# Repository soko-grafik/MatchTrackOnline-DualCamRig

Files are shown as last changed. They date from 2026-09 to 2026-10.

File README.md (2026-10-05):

# 📷 Dual DJI Osmo Action 4 Rig (80° V-Mount)






<p align="center">
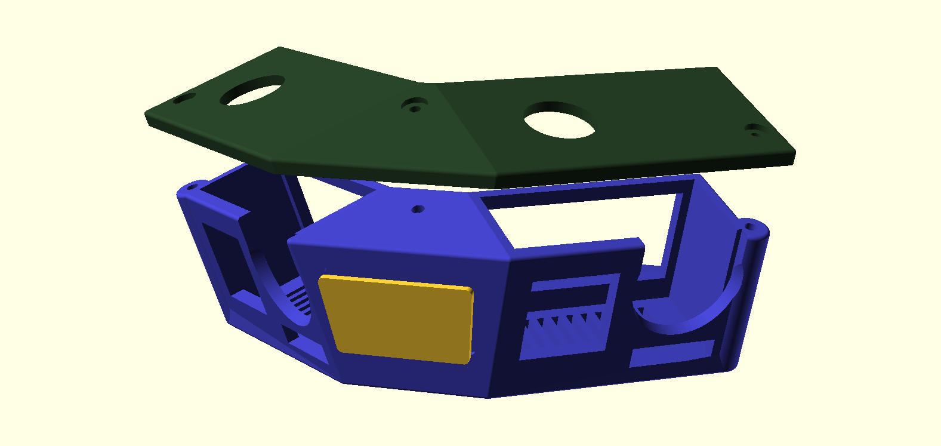
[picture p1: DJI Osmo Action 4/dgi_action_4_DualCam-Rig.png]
Dual DJI Osmo Action 4 Rig Preview
  
</p>

Ein professionelles, vollständig parametrisches 3D-Druck-Rig für **zwei DJI Osmo Action 4** Kameras, konstruiert in **OpenSCAD**.

Entwickelt für Weitwinkel-Aufzeichnungen, Stereo-Setups, Sport-Tracking und Livestreaming. Das Gehäuse bietet ein durchdachtes Kabel- und Energiemanagement mit dauerhafter USB-C-Stromversorgung, einem massiven **Rain Shield (Regenschutz)** für wetterfeste Außeneinsätze sowie einer **optionalen, in OpenSCAD zuschaltbaren Powerbank-Garage**.

---

## 📑 Inhaltsverzeichnis

- [✨ Features](#-features)
- [🛠️ Stückliste (BOM) & Hardware](#️-stückliste-bom--hardware)
- [📂 Projekt- & Dateistruktur](#-projekt--dateistruktur)
- [🖨️ 3D-Druck & Render-Modi](#️-3d-druck--render-modi)
  - [OpenSCAD Render-Modi](#openscad-render-modi)
  - [Druckempfehlungen & Slicer-Einstellungen](#druckempfehlungen--slicer-einstellungen)
- [⚙️ Parametrische Anpassung](#️-parametrische-anpassung)
- [🚀 Montageanleitung](#-montageanleitung)
- [☕ Support & Spenden](#-support--spenden)

---

## ✨ Features

- **📐 Präzise Geometrie:** 80° horizontale Spreizung und konfigurierbarer Neigungswinkel (Tilt, z. B. 20° nach unten gerichtet).
- **🌧️ Rain Shield Deckel:** Alternativer Top-Cover-Deckel mit breiter Krempe und bündigen Schraubensenkungen – maximaler Schutz vor Regen ohne Sichtfeldeinschränkung der Linsen.
- **⚡ Continuous Power:** Saubere USB-C-Aussparungen an beiden Kamera-Bays zur direkten Verkabelung für dauerhafte externe Stromversorgung.
- **🔋 Optionale Powerbank-Garage (nur via OpenSCAD):** Kann bei Bedarf parametrisch über OpenSCAD (`pb_enable = true`) im vorderen "V" des Rigs aktiviert und maßgeschneidert werden. In den beiliegenden Standard-Druckdateien (.3mf / .stl) ist das Gehäuse standardmäßig ohne Powerbank-Schacht ausgeführt.
- **❄️ Thermomanagement:** Strategisch platzierte Belüftungsschlitze (*Ventilation Slots*) verhindern Hitzestau bei Daueraufnahmen.
- **🏷️ Individualisierbar:** Frontseitig eingelassenes Trapez-Emblem für eigenes Branding (ideal für Single- oder Multi-Color-Druck).
- **🔩 Solide Stativaufnahme:** Integrierter Kragen für ein standardmäßiges 1/4"-Stativgewinde an der massiven Unterseite.

---

## 🛠️ Stückliste (BOM) & Hardware

| Komponente | Anzahl | Beschreibung / Empfehlung |
| :--- | :---: | :--- |
| **Kameras** | 2× | DJI Osmo Action 4 |
| **Gewindeeinsätze (Base)** | 3× | M3 Einschmelzmuttern / Heat-Set Inserts (z. B. Ruthex M3 × 5,7 mm) |
| **Schrauben (Deckel)** | 3× | M3 Zylinderkopf- oder Innensechskantschrauben (Länge passend zum Deckel) |
| **Stativgewinde** | 1× | 1/4"-20 UNC Gewindeeinsatz / Einschmelzmutter für Kamerastative |
| **USB-Kabel** | 2× | Kurze USB-C auf USB-C Kabel (idealerweise mit 90°-Winkelsteckern) |
| **Powerbank** *(optional)* | 1× | Nur erforderlich, falls die optionale Powerbank-Garage im SCAD-Modell aktiviert wird (`pb_enable = true`) |

---

## 📂 Projekt- & Dateistruktur

```text
├── DJI Osmo Action 4/
│   ├── dgi_action_4_DualCam-Rig.png    # 3D-Vorschau / Render-Bild
│   ├── dgi_action_4_DualCam-Rig.scad   # Parametrisches OpenSCAD-Hauptmodell
│   ├── 3mf Files/                      # Vorbereitete Slicer-Dateien (Bambu Studio / PrusaSlicer)
│   │   ├── base.3mf                    # Hauptgehäuse
│   │   ├── cover.3mf                   # Kompakter Standarddeckel
│   │   ├── cover_with_shield.3mf       # Deckel mit Regenschutz (Rain Shield)
│   │   └── emblem.3mf                  # Front-Trapez Emblem
│   └── stl Files/                      # Exportierte Standard-STLs zum Direktdruck
│       ├── base.stl
│       ├── cover.stl
│       ├── cover_with_shield.stl
│       └── emblem.stl
└── README.md                           # Dokumentation
```

---

## 🖨️ 3D-Druck & Render-Modi

### OpenSCAD Render-Modi

Die STL-Generierung der Einzelteile erfolgt über die Variable `RENDER_MODE` im Quellcode ([`dgi_action_4_DualCam-Rig.scad`](./DJI%20Osmo%20Action%204/dgi_action_4_DualCam-Rig.scad)):

1. Parameter `RENDER_MODE` in der `.scad`-Datei auf das gewünschte Bauteil setzen.
2. <kbd>F6</kbd> drücken (Vollständiges Rendern).
3. <kbd>F7</kbd> drücken (Als STL exportieren).

| `RENDER_MODE` | Bauteil | Beschreibung |
| :--- | :--- | :--- |
| `"base"` | **Hauptgehäuse** | Rig-Basis mit Kameraschächten & Stativkragen (Powerbank-Garage optional via SCAD zuschaltbar) |
| `"shield"` | **Rain Shield Deckel** | Regenschutz-Deckel (wird automatisch flach aufs Druckbett gelegt) |
| `"top"` | **Standard Deckel** | Flacher, kompakter Deckel ohne Überhang |
| `"emblem"` | **Front-Emblem** | Trapez-Insert für Front-Branding zum Einklicken oder Einkleben |

### Druckempfehlungen & Slicer-Einstellungen

Für maximale Robustheit und Witterungsbeständigkeit am Stativ empfiehlt sich kohlefaserverstärktes oder hitzebeständiges Filament wie **PETG-CF**, **PETG** oder **ASA/ABS**.

| Parameter | Empfohlener Wert | Details & Tipps |
| :--- | :--- | :--- |
| **Material** | **PETG-CF** / PETG / ASA | CF-Varianten bieten optimale Steifigkeit und ein sauberes mattes Finish |
| **Wandlinien (Walls)** | **4 – 5** | Wichtig für mechanische Stabilität und sicheren Halt der Einschmelzmuttern |
| **Infill** | **20% – 30% Gyroid** | Ausgezeichnete Stabilität bei gleichmäßigem Materialeinsatz |
| **Schichthöhe** | **0.16 – 0.20 mm** | 0.20 mm Standard liefert perfekte Ergebnisse |
| **Support (Base)** | **Normal / Tree Support** | Nötig für Kameraschächte und Überhänge (sowie Powerbank-Einschub, falls in SCAD aktiviert) |
| **Support (Shield/Top)** | **Keine** | Liegen flach auf dem Druckbett auf und drucken ohne Stützen |

---

## ⚙️ Parametrische Anpassung

Das Modell ist vollständig parametrisch aufgebaut. Alle Kernabmessungen können im oberen Bereich der [`dgi_action_4_DualCam-Rig.scad`](./DJI%20Osmo%20Action%204/dgi_action_4_DualCam-Rig.scad) individuell konfiguriert werden:

```openscad
// ==========================================
// PARAMETER & KONFIGURATION
// ==========================================

// Powerbank-Halterung (OPTIONAL – standardmäßig deaktiviert)
pb_enable       = false;  // true = Powerbank-Garage im V-Bereich generieren
pb_width        = 40.0;   // Breite der Powerbank in mm
pb_length       = 60.0;   // Länge/Tiefe der Powerbank in mm
pb_height       = 20.0;   // Höhe der Powerbank in mm

// Regenschutz
shield_overhang = 12.0;   // Überstand der Krempe (typisch 8.0 - 18.0 mm)

// Rig-Geometrie
rig_angle       = 80.0;   // Horizontaler Spreizwinkel zwischen den Kameras
cam_pitch       = 20.0;   // Neigungswinkel nach unten (Tilt)
```

---

## 🚀 Montageanleitung

```text
  [ Rain Shield / Top Cover ]
              │  (3× M3 Schrauben)
              ▼
  ┌─────────────────────────┐
  │  [Cam 1]  (PB)  [Cam 2] │ ◄── Kameras & (optional Powerbank)
  │       [Main Base]       │
  └─────────────────────────┘
              ▲
              │  (1× 1/4" Stativadapter)
        [ 1/4" Tripod ]
```

1. **Einschmelzmuttern einsetzen:**
   - Die 3× M3-Gewindeeinsätze mit einer Lötkolbenspitze (ca. 220–250 °C) vorsichtig und gerade in die vorgesehenen Schraubtürme der Base einschmelzen.
2. **Stativgewinde montieren:**
   - Den 1/4"-Stativ-Gewindeeinsatz an der Unterseite der Base bündig einpressen bzw. einschrauben.
3. **(Optional) Powerbank einschieben:**
   - *Nur relevant, falls in OpenSCAD `pb_enable = true` gewählt wurde:* Die Powerbank von hinten horizontal in den zentralen Schacht einschieben (das vordere Loch dient bei Bedarf als Auswerfer).
4. **Kameras & Verkabelung:**
   - Beide DJI Osmo Action 4 Kameras in ihre Halterungen einsetzen.
   - USB-C-Kabel (z. B. von einer externen Stromversorgung oder der optionalen internen Powerbank) durch die Aussparungen an den Ladebuchsen der Kameras anschließen.
5. **Deckel verschrauben:**
   - *Rain Shield* oder *Top Cover* aufsetzen und mit den 3× M3-Schrauben handfest fixieren. Die Schraubenköpfe versenken sich bündig in den dafür vorgesehenen Vertiefungen.

---

## ☕ Support & Spenden

**MatchTrack Online** ist ein unabhängiges Projekt, das mit viel Herzblut für Trainer und Vereine entwickelt wird. Der Betrieb von Testservern, die Bereitstellung von Updates und die kontinuierliche Entwicklung neuer Funktionen erfordern jedoch viel Zeit und laufende Ressourcen.

Wenn dir die Plattform bei deiner Videoanalyse, Spielvorbereitung und Trainingsarbeit hilft und du die Weiterentwicklung unterstützen möchtest, freue ich mich riesig über deine Unterstützung und einen Kaffee!

<p align="center">
  <a href="https://paypal.me/soko21061983" target="_blank">
    
  </a>
  &nbsp;&nbsp;
  <a href="https://paypal.me/soko21061983" target="_blank">
    
  </a>
</p>

---

<p align="center">
  Made with ⚽ for coaches and teams.
</p>

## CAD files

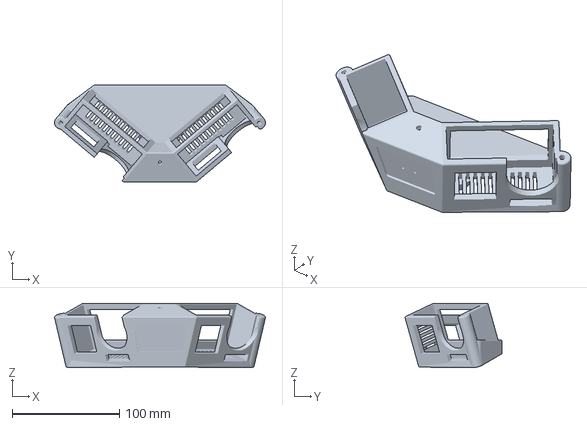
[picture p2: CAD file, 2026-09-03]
DJI Osmo Action 4/3mf Files/base.3mf
197.0 x 90.5 x 60.0 mm

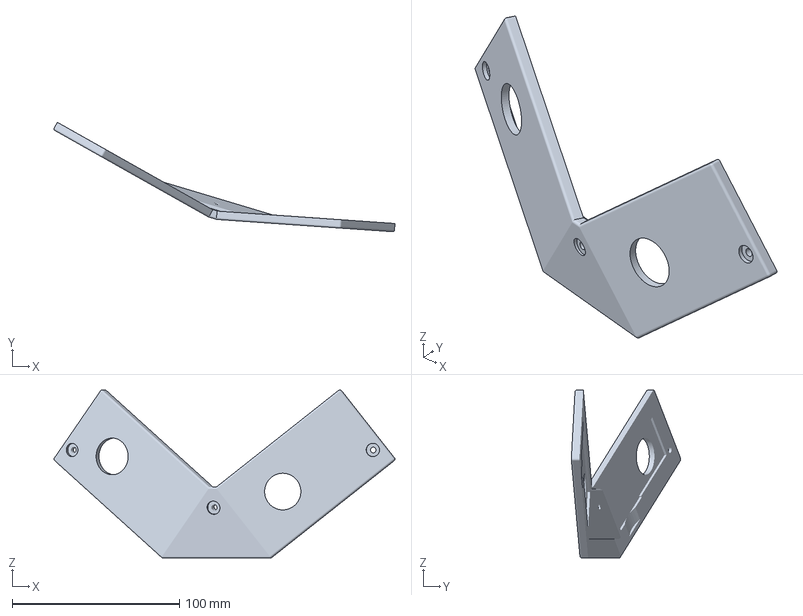
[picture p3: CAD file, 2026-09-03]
DJI Osmo Action 4/3mf Files/cover_with_shield.3mf
204.2 x 65.5 x 100.6 mm

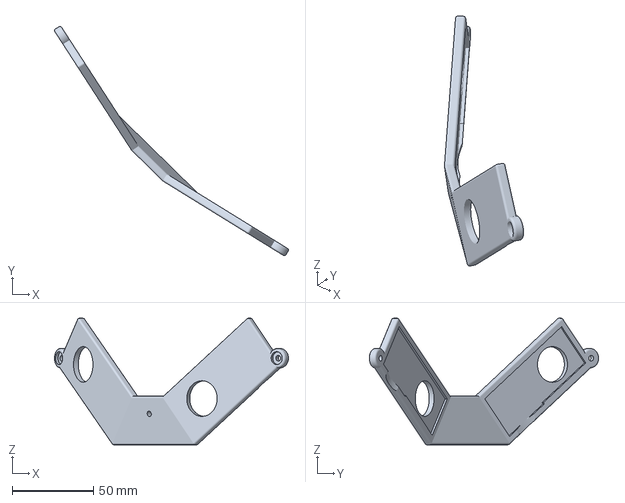
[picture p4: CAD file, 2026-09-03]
DJI Osmo Action 4/3mf Files/cover.3mf
144.4 x 141.5 x 78.1 mm

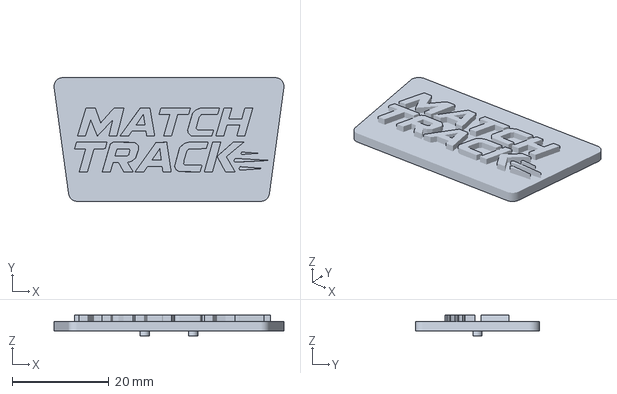
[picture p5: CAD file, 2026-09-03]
DJI Osmo Action 4/3mf Files/emblem.3mf
47.6 x 25.6 x 4.25 mm

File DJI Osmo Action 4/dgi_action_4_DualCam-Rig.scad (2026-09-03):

// ====================================================================
// PARAMETRISCHES 80° DUAL DJI OSMO ACTION 4 RIG 
// (15° GENEIGT, BELÜFTUNGSSCHLITZE, KONISCHER LINSEN-FREIRAUM)
// ====================================================================

$fn = 64;

/* [Ansichts-Optionen] */
RENDER_MODE = "base"; // [assembly:Gesamter Zusammenbau, base:Nur Hauptgehaeuse, top:Normaler Deckel, shield:Regenschutz-Deckel, emblem:Das Trapez-Emblem]

/* [Regenschutz / Shield] */
shield_enable     = true; // Regenschutz-Deckel im Assembly generieren (ersetzt den normalen Deckel)
shield_overhang   = 8.0;  // Wie weit der Schirm an den Seiten übersteht (in mm)
shield_thickness  = 5;    // Dicke des Schirms an den Rändern (Krempe)

/* [Ladebuchse & Powerbank] */
// Öffnung für den USB-C Anschluss
charge_port_w   = 18.0;   // Breite der Öffnung
charge_port_h   = 32.0;   // Höhe der Öffnung
charge_port_y   = 4.0;    // Y-Verschiebung der Ladebuchse

// Powerbank-Halterung im vorderen V-Bereich (Horizontales Einschieben von hinten)
pb_enable       = false;   // Powerbank-Halterung aktivieren
pb_width        = 40.0;   // Breite der Powerbank (X-Achse)
pb_length       = 60.0;   // Einstecktiefe der Powerbank (Y-Achse)
pb_height       = 20.0;   // Dicke/Höhe der Powerbank (Z-Achse)
pb_wall         = 3.0;    // Wandstärke der Halterung
pb_y_offset     = -40.0;  // Position des Blocks nach VORNE (Negative Y-Achse = spitzes Ende)

/* [Emblem & Branding (Trapez auf dem Kopf)] */
emblem_w_top    = 48.0;   
emblem_w_bot    = 42.0;   
emblem_h        = 26.0;   
emblem_r        = 2.0;    
emblem_thick    = 2.0;    
emblem_recess   = 0;    
emblem_pin_dia  = 2.0;    
emblem_pin_dist = 10.0;   
emblem_pin_h    = 1.0;    
emblem_pitch_c  = 36.5;   

// --- Position Gehäuse ---
logo_base_y     = 33.0;
logo_base_z     = 15.0;

/* [Wand-Verstärkung (Front-Display)] */
inner_wall_reinforcement = 1.0; 

/* [Kamera-Abmessungen: DJI Osmo Action 4] */
cam_width       = 71.4;
cam_height      = 44.8;
cam_depth       = 29.0;
cam_clearance   = 0.6;    

/* [Rig-Geometrie & Winkel] */
rig_angle       = 80.0;   
cam_pitch       = 20.0;   
wall_thick      = 4.0;    
floor_thick     = 5;    
top_thick       = 5.0;    
base_depth      = 0;   

/* [Premium-Design] */
edge_r          = 1.2;    

/* [Ausschnitte - Base & Linsen] */
lens_dia        = 34.0;
lens_cone_dia   = 38.0;   
lens_offset_x   = 18.5;
screen_w        = 28.0;
screen_h        = 28.0;
screen_offset_x = -17.0;
button_slot_w   = 28.0;   
button_slot_h   = 34.0;   

// --- Konischer Linsen-Ausschnitt Deckel ---
top_lens_dia    = 42.0;   
top_lens_cone_d = 42.0;   
top_lens_off_x  = 21.7;   
top_lens_off_z  = 29.0;   

/* [Ausschnitte - Deckel (Top)] */
top_cutout_w_factor = 0.5;
rec_btn_dia     = 22.0;   
rec_btn_off_x   = 17.0;   
rec_btn_off_y   = 0.0;    

/* [Belüftungs-Parameter] */
vent_slot_w     = 2.5;    
vent_slot_space = 5;    

/* [Befestigung: Schrauben & Muttern] */
insert_dia      = 4.0;    
insert_depth    = 5.0;    
screw_hole_dia  = 3.5;    
screw_head_dia  = 8.0;    
screw_head_depth= 2;    

// Zentrales Loch & Stativ
center_screw_y     = 6.0;   
tripod_hole_dia    = 7.2;    
tripod_boss_top_d  = 60.0;   
tripod_boss_bot_d  = 30.0;   
tripod_boss_h      = 20.0;   

// Ohren-Löcher
insert_boss_dia = 12;   
bay_screw_y_pos = 14.0;   
bay_screw_x_out = 3.0;    


// ====================================================================
// BERECHNETE MASSE (GLOBAL)
// ====================================================================
c_w = cam_width + cam_clearance;
c_h = cam_height + cam_clearance;
c_d = cam_depth + cam_clearance;
half_angle = rig_angle / 2;

outer_w = c_w + 2 * wall_thick;
outer_d = c_d + 2 * wall_thick;
outer_h = c_h + floor_thick;

bay_screw_off_y = bay_screw_y_pos;
bay_screw_base_x = (c_w / 2) + (wall_thick / 2) + bay_screw_x_out; 


// ====================================================================
// 3D-VERRUNDUNGS-MODULE
// ====================================================================

module r_box_3d(w, d, h, r, flat_bottom=false, flat_top=false) {
    hull() {
        for (x = [w/2-r, -w/2+r]) {
            for (y = [d/2-r, -d/2+r]) {
                translate([x, y, 0]) {
                    if (flat_bottom) cylinder(r=r, h=0.001);
                    else translate([0, 0, r]) sphere(r=r);
                    
                    translate([0, 0, h])
                    if (flat_top) translate([0, 0, -0.001]) cylinder(r=r, h=0.001);
                    else translate([0, 0, -r]) sphere(r=r);
                }
            }
        }
    }
}

module rounded_cylinder(d, h, r, flat_bottom=false, flat_top=false) {
    hull() {
        if (flat_bottom) cylinder(d=d, h=0.001);
        else translate([0, 0, r]) rotate_extrude() translate([d/2 - r, 0, 0]) circle(r=r);
        
        translate([0, 0, h])
        if (flat_top) translate([0, 0, -0.001]) cylinder(d=d, h=0.001);
        else translate([0, 0, -r]) rotate_extrude() translate([d/2 - r, 0, 0]) circle(r=r);
    }
}

module bay_outer_profile(is_left, h_val, flat_bottom=false, flat_top=false) {
    bay_screw_off_x = is_left ? -bay_screw_base_x : bay_screw_base_x;
    union() {
        r_box_3d(outer_w, outer_d, h_val, edge_r, flat_bottom, flat_top);
        translate([bay_screw_off_x, bay_screw_off_y, 0])
            rounded_cylinder(d = insert_boss_dia, h = h_val, r=edge_r, flat_bottom=flat_bottom, flat_top=flat_top);
    }
}

module bay_corner(is_left, corner_x, corner_y, z_offset, h_val, r, flat_bottom=false, flat_top=false) {
    yaw = is_left ? half_angle : -half_angle;
    tx = is_left ? -outer_w/2 + 0.05 : outer_w/2 - 0.05;
    ty = outer_d/2;
    
    rotate([0, 0, yaw])
        rotate([-cam_pitch, 0, 0])
        translate([tx, ty, z_offset])
        translate([corner_x, corner_y, 0])
        hull() {
            if (flat_bottom) cylinder(r=r, h=0.001);
            else translate([0, 0, r]) sphere(r=r);
            
            translate([0, 0, h_val])
            if (flat_top) translate([0, 0, -0.001]) cylinder(r=r, h=0.001);
            else translate([0, 0, -r]) sphere(r=r);
        }
}

module center_fill_bridge(z_offset, h_val, flat_bottom=false, flat_top=false, is_shield=false) {
    hull() {
        bay_corner(true, outer_w/2 - edge_r, -outer_d/2 + edge_r, z_offset, h_val, edge_r, flat_bottom, flat_top);
        bay_corner(true, outer_w/2 - edge_r,  outer_d/2 - edge_r, z_offset, h_val, edge_r, flat_bottom, flat_top);
        bay_corner(false, -outer_w/2 + edge_r, -outer_d/2 + edge_r, z_offset, h_val, edge_r, flat_bottom, flat_top);
        bay_corner(false, -outer_w/2 + edge_r,  outer_d/2 - edge_r, z_offset, h_val, edge_r, flat_bottom, flat_top);
    }
    
    if (is_shield) {
        oh = shield_overhang;
        hull() {
            bay_corner(true,  (outer_w/2 - edge_r) + oh, (-outer_d/2 + edge_r) - oh, z_offset, shield_thickness, edge_r, true, false);
            bay_corner(false, (-outer_w/2 + edge_r) - oh, (-outer_d/2 + edge_r) - oh, z_offset, shield_thickness, edge_r, true, false);
            bay_corner(true,  (outer_w/2 - edge_r) + oh, (outer_d/2 - edge_r) + oh, z_offset, shield_thickness, edge_r, true, false);
            bay_corner(false, (-outer_w/2 + edge_r) - oh, (outer_d/2 - edge_r) + oh, z_offset, shield_thickness, edge_r, true, false);
        }
    }
}

module center_fill_bridge_cavity(wall, top_wall) {
    z_off = -15; 
    h_val = outer_h - top_wall - z_off;
    
    hull() {
        bay_corner(true,  outer_w/2 - edge_r + 0.1, -outer_d/2 + edge_r + wall, z_off, h_val, edge_r, true, true);
        bay_corner(true,  outer_w/2 - edge_r + 0.1,  outer_d/2 - edge_r - wall, z_off, h_val, edge_r, true, true);
        bay_corner(false, -outer_w/2 + edge_r - 0.1, -outer_d/2 + edge_r + wall, z_off, h_val, edge_r, true, true);
        bay_corner(false, -outer_w/2 + edge_r - 0.1,  outer_d/2 - edge_r - wall, z_off, h_val, edge_r, true, true);
    }
}


// ====================================================================
// MODULE: BELÜFTUNGSSCHLITZE & KAMERA-AUSSCHNITTE
// ====================================================================

module camera_lens_cutout() {
    translate([lens_offset_x + 2.1, -c_d/2 - wall_thick - 4.1, c_h/2 + 7])
        rotate([-90, 0, 0]) 
            cylinder(d1 = lens_cone_dia, d2 = lens_dia, h = wall_thick + 4.2);
}

module top_cover_lens_cutout() {
    translate([top_lens_off_x, -c_d/2 - wall_thick - 5.1, top_lens_off_z])
        rotate([-90, 0, 0]) 
            cylinder(d1 = top_lens_cone_d, d2 = top_lens_dia, h = wall_thick + 5.2);
}
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

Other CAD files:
DJI Osmo Action 4/stl Files/base.stl
DJI Osmo Action 4/stl Files/cover.stl
DJI Osmo Action 4/stl Files/cover_with_shield.stl
DJI Osmo Action 4/stl Files/emblem.stl
